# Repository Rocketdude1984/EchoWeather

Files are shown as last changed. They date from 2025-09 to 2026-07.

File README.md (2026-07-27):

# EchoWeather: DIY weather station and app
A personal project to design, build, and program a working weather station that connects to a database and smart phone app. Collected data will then be used to train an AI model that will predict future weather variables.

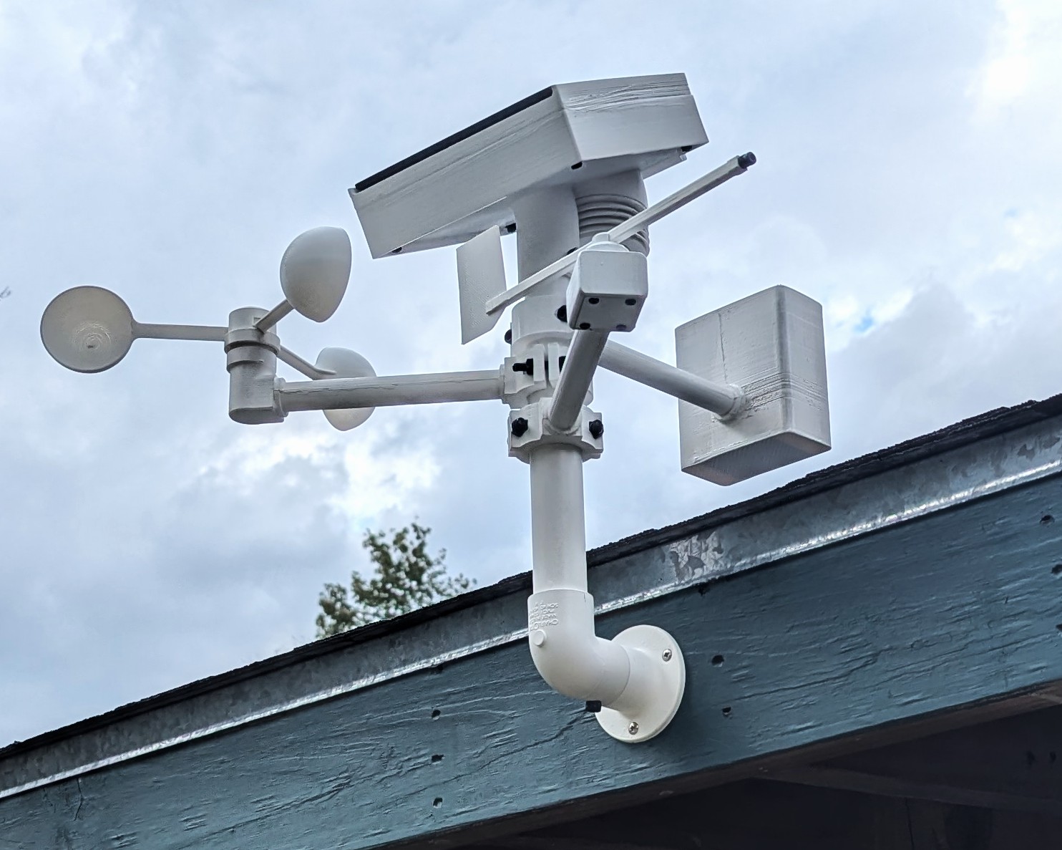
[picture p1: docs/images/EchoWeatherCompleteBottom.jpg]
Diagram


## Weather Variables

* Wind Speed
* Wind Direction
* Temperature
* Humidity
* Pressure
* Ambient Light
* UV Light
* Rain

## Sensors and Components
1. XIAO ESP32C3: https://www.amazon.com/dp/B0DGX3LSC7?ref=ppx_yo2ov_dt_b_fed_asin_title&th=1
2. BME280 breakout module: https://www.amazon.com/dp/B0DHPCFJD6?ref=ppx_yo2ov_dt_b_fed_asin_title&th=1
3. AS5600 Magnetic Encoder: https://www.amazon.com/dp/B094F8H591?ref=ppx_yo2ov_dt_b_fed_asin_title&th=1
4. Solar Power Manager Board: https://www.amazon.com/dp/B0FQP915R9?ref_=ppx_hzsearch_conn_dt_b_fed_asin_title_2
5. LTR390-UV Ultraviolet Sensor: https://www.amazon.com/dp/B0CHJL143Z?ref=ppx_yo2ov_dt_b_fed_asin_title&th=1
6. VEML7700 Ambient Light Sensor: https://www.amazon.com/dp/B09KGYF83T?ref=ppx_yo2ov_dt_b_fed_asin_title
7. 6V3W Waterproof Solar Panel: https://www.amazon.com/dp/B0CS364JGG?ref=ppx_yo2ov_dt_b_fed_asin_title&th=1

## Modules
The weather station will be built in 4 modules.
1. Power and basic variables (Main module)
2. Wind vane
3. Anemometer
4. Rain gauge

Each module will be connected together to the main module where all collected data will be sent to the cloud.

## Power
The station will be powered by two 18650s in parallel. To keep the battery charged, the station will have a built in 6V3W solar panel that charges the battery through a solar power management board.

## Materials
Most of the station is printed with PETG which should be able to withstand fairly high outdoor temperatures and resist fading or cracking. 1" PVC pipe is used for the main support to hold each module of the station. For extra UV protection a few coats of white spray paint will be used.

## Code
Download full code folder and make sure to replace the credentials in cred.h with your own information for WiFi and google sheet connectivity. Read this article for getting IDs and keys for the credentials: [https://randomnerdtutorials.com/esp32-datalogging-google-sheets/].

## App
The app was designed in MIT App Inventor and I have included the .aia file that you can import into App Inventor and configure to your project. (the only required configuration is the URL to your app script for sheets, re: docs/Google_sheet_setup).

## Calibration 
After allowing the system to run for a few months I compared known weather data from reliable sources with the data gathered from the station. Most values were close to the true ones, but I did calculate some scaling factors for the station. See the Calibration and Changes page under docs.

## One-year Thoughts
The Station has been running near constant for a year now (a few hiccups caused me to miss a few days). I did some things right and lot wrong that I would do different if I ever made another station.

### What I did right
- The Wind direction sensor worked perfectly.
- The Rain sensor did work, but how on that in the next section.
- The batteries only lost power 2 times (once because of an extended cloudy period > 7 days of cloulds, and once because of the batteries overheating).
- The app worked great for the whole test period
- The PETG and paint held up great even in the extreme heat.
- The enclosure was completely waterproof.

### What I would do differently
- lithium-polymer was the wrong choice for the Texas heat, I had 2 sets of lipos overheat and become unusable because of the Texas heat and the lack of active or passive cooling. I would instead switch to LiFePo4 cells with a thermal sensor on the cells that would activate a small fan to vent out the hot air in the enclosure.
- The ESP32C3 Xiao board just didn't have enough GPIO pins, I had to use a boot pin for the rain sensor that could sometimes cause the station to not turn on if it was stuck high. I would use a standard ESP32 dev board.
- I would make sure to have a quick-disconnect function for the staion and the mount. I had to take the station down quite a few times and unscrewing the mount and holding the station was very difficult to do on a ladder. I would make sure to use a connection that only needed a single thumb screw to remove the station.
- I would also make a custom holder for the staion when I am working on it because it I did not like the way the anemometer and wind vane would bend on when the station sat on the desk.
- The BME sensor did not prove to be super accurate either. The temperature was always 10-15 degrees higher than the true temperature in temps over 90 degrees, but yet correct under about 80 degrees. The humidity sensor just has been 100% for about 3 months and not changed, but it never seemed that accurate before.
- The lux sensor also didn't really correlate to any real values, but it did work for relative measurements.
- The solar board I installed half-way through the test was much better than the first board I had, but I would need to find one that works with the lower voltage of the LiFePo4 cells I would use.
- I would also be great for the station to start a new spreadsheet for logging data every year because the app took a while to load a years worth of data from the spreadsheet.

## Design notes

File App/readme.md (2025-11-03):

# App Notes

The app for the EchoWeather system was design in Gimp and built in MIT App Inventor

I could not include the APK because if you want to make this project you will have to edit a URL in App Inventor in order to connect to your app script that fetches data from your Google Sheet (re: fig. 3).

## Displayed Values
* Temperature
* Humidity
* Pressure
* Average wind speed
* Gust wind speed
* Cardinal wind direction
* rain rate in in/hr
* light level
* UV level
* Battery Voltage
* Location of Weather Station
* Last updated time
* Icon of type of weather based on light, rain, and temperature
* 24 Hour high and low values for temperature, wind, rain, and humidity

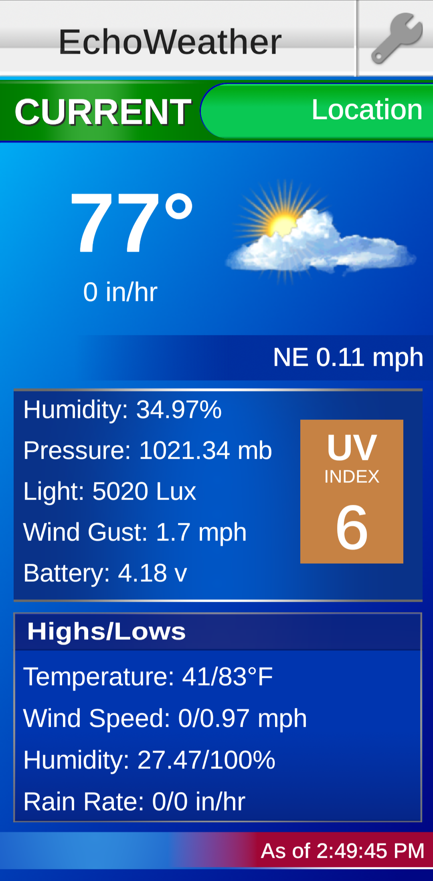
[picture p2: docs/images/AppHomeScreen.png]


fig. 1 - EchoWeather App homescreen

The App also has a settings screen for changing units on temperature, wind speed, and daylight saving or standard time, see fig. 2.

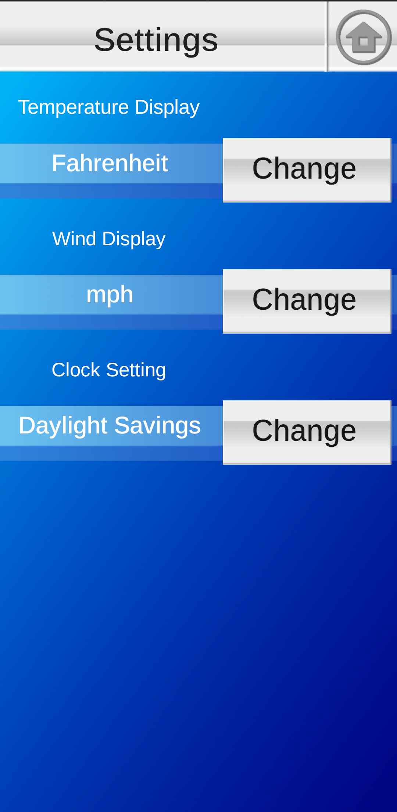
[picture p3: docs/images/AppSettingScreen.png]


fig. 2 - The settings screen for the app to change select units and time

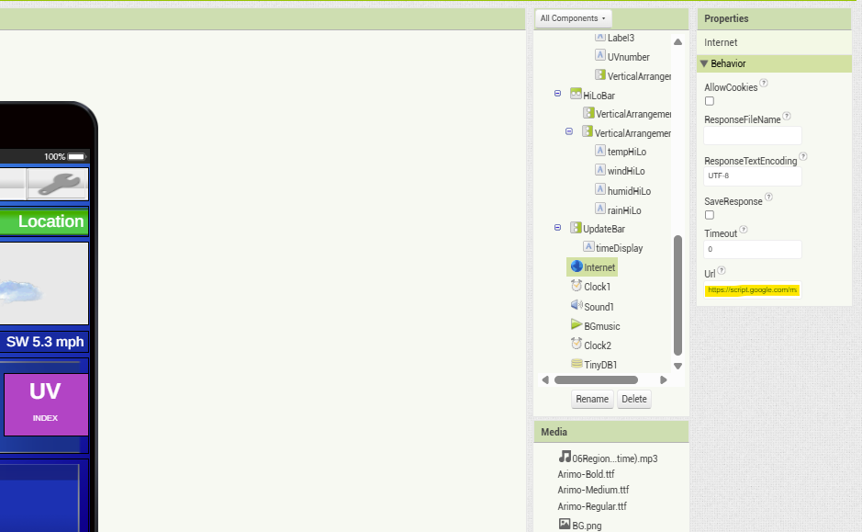
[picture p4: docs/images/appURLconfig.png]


fig. 3 - The URL component you must change to match your own app script in App Inventor

See Google Sheets setup in the docs folder on how to get this URL for your own project.

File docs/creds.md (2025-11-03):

## References
Project inspired by: Nikodem Bartnik, Weather Station is The Best DIY Project EVER. https://youtu.be/U0kPgFcALac?si=J3OKKQZrQx6dV7NR

3D models: wt29, Anemometer, Windvane and Raingauge - 3D Printed and ESP8266 Enabled. Internet Connected and Logging. https://www.instructables.com/Anemometer-3D-Printed-With-Internet-Logging/

App resources:
App images: The Spriter's Resource: http - //www.spriters-resource.com/wii/forecastchannel/asset/68551/?source=genre
App Background music: KHinsider.com - https://downloads.khinsider.com/game-soundtracks/album/wii-forecast-channel
App design software: MIT App Inventor - https://appinventor.mit.edu/

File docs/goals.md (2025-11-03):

# Project Goals

- [x] Design, build, and program a small weather station using a variety of sensors.
- [x] Construct station using 3D printable prints and cheap, commercially available parts.
- [x] Design a smart phone app to display current weather variables.
- [ ] Build and deploy multiple stations across wide geographic area.
- [ ] Build and train AI model using collect weather data for future weather predictions.
- [ ] Update smart phone app to include predicted forecast.

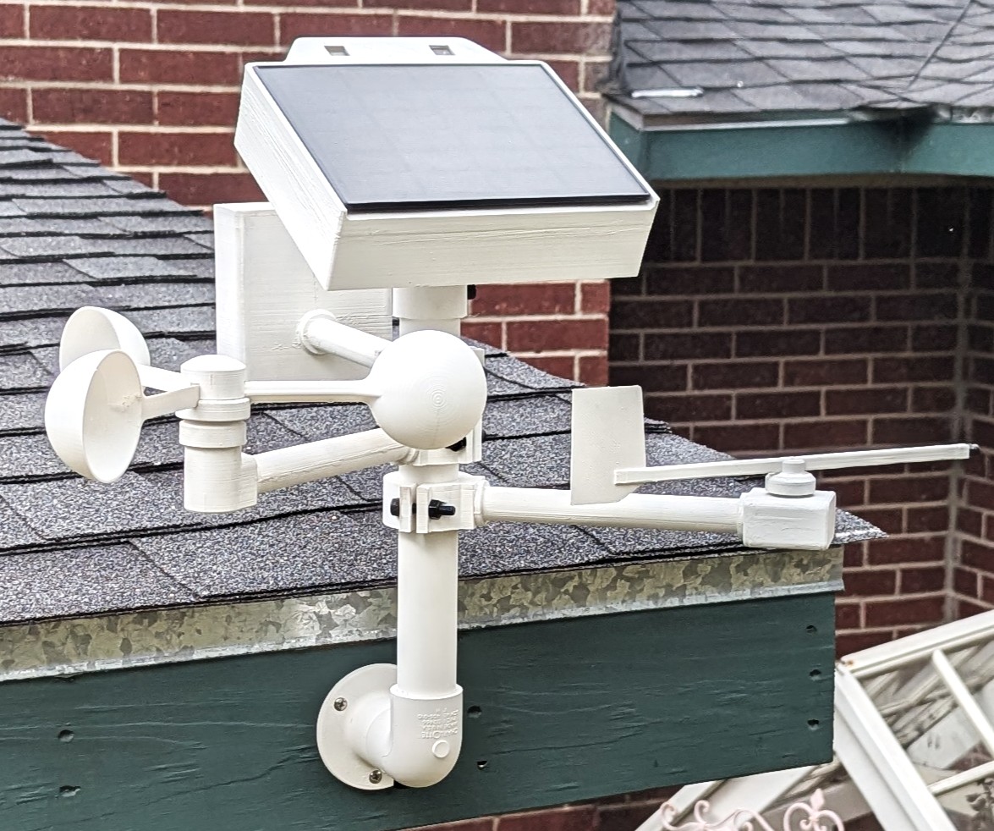
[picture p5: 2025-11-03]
docs/images/EchoWeatherCompleteTop.jpg

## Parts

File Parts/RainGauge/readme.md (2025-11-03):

# Notes

## Construction

1. Print all parts of Rain Gauge MAKE SURE TO USE "LINES" OR SIMILAR INFILL PATTERN FOR TOP AND BOTTOM GRID PRINTS AND SET TOP AND BOTTOM WALLS TO 0. There should be no top or bottom walls to these parts as they are supposed to let water through while blocking wasp and other insects from making nest inside the rain gauge. see fig. 1.
2. Drill, file, and sand parts to ensure good fittment between prints.
3. Install 2 ball bearings into EchoWeather_bucket.
4. Cut 4mm to length to span bucket and fulcrum parts.
5. Use washers to act as spacers and to reduce frictiion between fulcrum and bucket
6. Install magnet in bucket WITH SOUTH POLE FACING OUTWARDS.

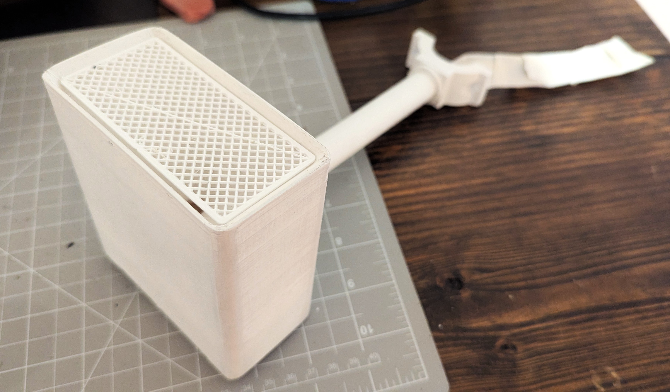
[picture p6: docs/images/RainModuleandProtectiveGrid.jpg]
Diagram


fig. 1 - Completed Rain Gauge with protective grids for insect protection

## Components

* 2x5mm round magnet
* (2) 8x4x3 ball bearings
* 4mm steel rod
* Assembled support rod (see support rod notes)

## Specs

This setup was calculated from test to be about 0.7mm (0.028in) for each tip of the bucket.
This module is not very sensitive to rain, and will probably be re-designed in the future. 
With a 5-min measuring interval, this module can only measure rain rates greater than 0.33 in/hr.

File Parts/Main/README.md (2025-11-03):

# Main Notes
## Main Box
1. Ensure there is enough glue to waterproof components.
2. Glue all parts together, unless screws or bolts are used, in this case use no glue.
3. Use Silicone based adhesive to seal joints.
4. Finish with bright white, satin spray paint.
5. Glue milk carton squares to cover UV and Lux sensor.

Components:
* (4) - M4x7 socket head bolts -- for holding bottom to enclosure
* (7) - M4x5x5 heated threaded inserts -- 4, for bottom bolts, 3 for stevenson screen connection
* (2) - M6x12 socket head bolts -- for securing box to PVC pip mounts at both ends
* (2) - M6 nuts
* (2) - M2.5x6 pan head bolts -- for VEML7700
* (2) - M2x4 socket head bolts -- for LTR390-UV
* 1/16" thick silicone sheet cut to fit channel in top of box (see image below)
* 1/16" thick acrylic sheet cut to fit viewing ports for light sensors (see image below)
* (2) - 18650 battery holders
* 1.5" OD PVC pipe (about 10" long)
* 1.5" 90° elbow fitting -- if mounting on a vertical surface
* About 3/4" square pieces of cut plastic milk gallon (to act as light diffuser for ambient light sensor and UV sensor).

*See electrical (WIP) for electrical components in main box.*

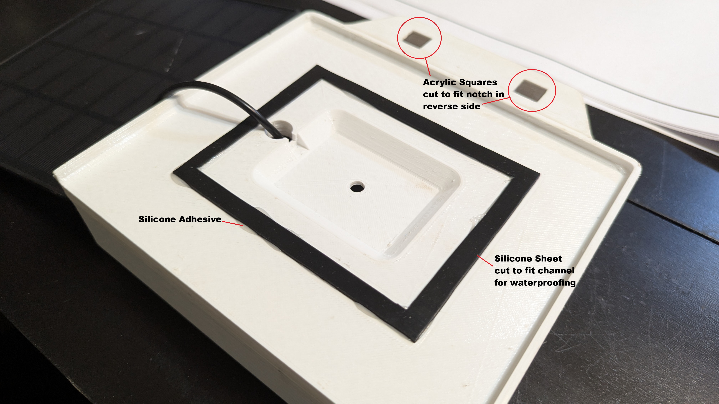
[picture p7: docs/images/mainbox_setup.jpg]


fig. 1 - waterproofing measures for Main Box

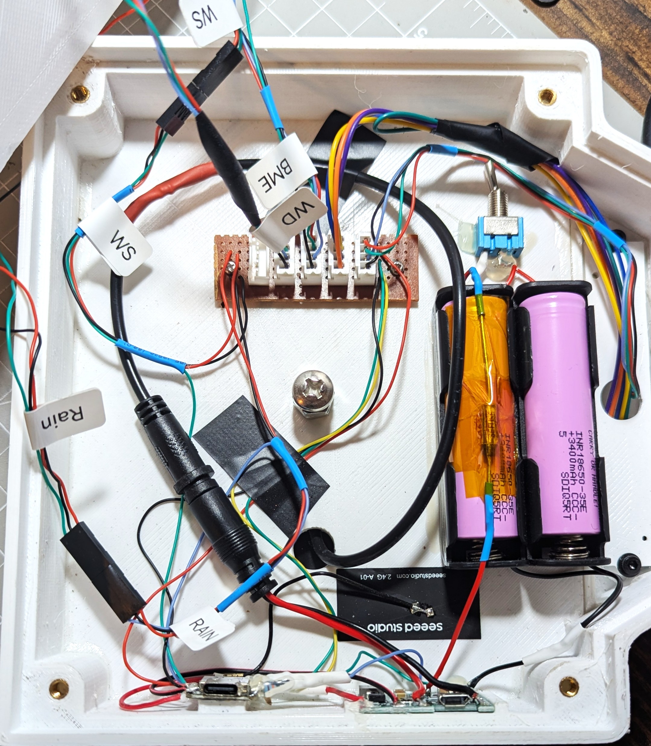
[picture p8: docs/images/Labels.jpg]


fig. 2 - Layout of components in Main Box

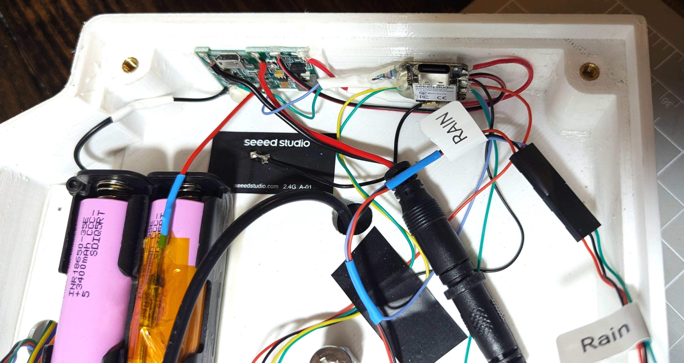
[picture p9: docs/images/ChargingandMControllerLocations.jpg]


fig. 3 - Location of Charging module and Microcontroller

## Stevenson Screen:
1. Print (4) total Rings for the stevenson screen (There is only one ring .stl file because they're of course identical)
2. Glue mounting plate for BME280 to top of stevenson screen (this is the only component for the screen that needs glue).

Components:
* (3) M4x30 socket head bolts
* M3x8 socket head bolt -- for mounting BME280
* M3 nut
* 1-3/4" x 1-5/16" sink strainer washer

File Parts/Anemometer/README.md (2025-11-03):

# Notes

REQUIRED FILES FOR ANEMOMETER
Download the following parts from the anemometer project by [wt29](https://github.com/wt29):
- [AnemometerBaseCap.stl](https://github.com/wt29/Anemometer/blob/main/stl/AnemometerBaseCap.stl)
- [AnemometerRotor.stl](https://github.com/wt29/Anemometer/blob/main/stl/AnemometerRotor.stl)
- [AnemometerRotorCap.stl](https://github.com/wt29/Anemometer/blob/main/stl/AnemometerRotorCap.stl)

These parts did need some minor modification by filing, drilling, and sanding, but they did work.

The EchoWeather_AnemometerEnclosure was used just as an adapter to make wt29's parts with this project's support rod.
New wind cups were also designed (EchoWeather_WindCupv3). These redesigned cups were more sensitive to lighter winds.

## Construction
1. Print 3 total wind cups
2. Some drilling is required to allow the 3144 hall-effect sensor to fit flush with surface of print (AnemometerBaseCap)
3. 3. Glue two 5x2mm magnets into bottom divots of rotor. MAKE SURE THE SOUTH POLE OF MAGNET IS FACING OUTWARD, the 3144 can only detect south magnetic poles, I used a test set up with an arduino and the 3144 sensor to know which pole was south.
4. Use a 4mm Threading die to cut threads into 4mm rod, about a 1/4".
5. Cut the rod to length to be used as axle.
6. Glue wind cups into rotor, ensuring each cup is pushed in all the way and level.
7. Glue 3144 sensor into rotor base cap and solder wiring to leads, BEFORE gluing the base cap to the anemometer enclosure.
8. Insert single ball bearing into rotor (bottom). printed part has slots for 2 bearings, but in testing 1 bearing provided less friction and more sensitivity.
9. Insert 4mm rod through rotor assembly and then into the base assembly. (I put a small washer in-between the two assesmblies to reduce friction)
10. Use lubricating oil to reduce friction between rotor and base at the washer.

## Components
- (2) 5x2mm magnets
- 8x4x3 ball bearing
- 4mm stainless steel rod, cut to length
- 3144 hall-effect sensor
- Support rod assembly (see supoort rod notes)

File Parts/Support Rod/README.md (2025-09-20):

# Notes for Support Rod
1. print (2) total support Rod halves to make the completed rod.
2. Enclose wiring for sensor in support rod BEFORE assembly.
3. Using glue to fasten the two support rod halves together and then the rod to the inner clamp.
4. The Outer clamp is held in with bolts and nuts.

# Components
* (2) - M6x25 socket head bolts
* (2) - M6 nuts

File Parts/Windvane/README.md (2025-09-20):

# Wind Vane

## Notes
1. Fasten the face, lid, and enclosure parts with waterproof adhesive.
2. Secure AS5600 sensor with IC side facing shaft.
3. Cut 4mm rod to length.
4. Glue included magnet with AS5600 to bottom of 4mm rod.
5. Use M4 nuts, washsers, and bolt to move CoM of wind vane to the mounting hole.
6. Use M6 washer to act as spacer between inner and outer rotor parts.

Components
- (4) M4x8 bolts - for securing AS5600 to enclosure
- (4) M3x8 bolts - for bottom lid
- 4mm stainless steel rod cut to length - for axle of wind vane
- M4x(8mm-16mm) bolt - for balancing wind vane, may need extra nuts or washers (I used M4x12 bolt with (2) M4 nuts).
- (5) M4x5x5 heated, threaded inserts - 4 for AS5600 mounting and 1 for the balancing bolt of wind vane
- (4) M3x4x4.2 heated, threaded inserts - for the bottom cover of the wind vane
- (2) 8x4x3mm ball bearings - one in each divot of the inner rotor part.
- Support rod assembly (see support rod notes)

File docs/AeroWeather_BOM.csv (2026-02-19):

Option 1
Component | Quantity | Cost | Cost/unit | Notes
BME280 | 2 | $12.89 | $4.30 | Temperature, Humidity, Presurre
ESP32C3 Xiao | 3 | $19.99 | $6.66 | Controller
LTR390-UV | 1 | $14.60 | $14.60 | UV sensor
PETG filament | 1 | $15.60 | $15.60 | Anemometer, wind vane, enclosure
AS5600 | 3 | $9.99 | $3.33 | Rotary Senor
Bearings 4mmIDx8mmODx3mmH | 10 | $8.69 | $0.87 | Bearings
Solar Power Manger | 1 | $16.29 | $16.29 | Charging and Boost Converter
VEML7700 | 2 | $12.99 | $6.50 | Light Sensor
6w solar panel | 1 | $18.99 | $18.99 | Solar Panel
1inOD PVC pipe | 1 | $5.41 | $5.41 | Mast
1inOD PVC 90 | 1 | $1.48 | $1.48 | Elbow
Krylon Spray Paint | 3 | $7.98 | $2.66 | UV protection
18650 Battery Holder | 5 | $5.98 | $1.20 | Holds the single 18650 cell
18650 Cells | 6 | $23.99 | $4.00 | Powers the station
 | Total Cost | $174.87 | $101.88

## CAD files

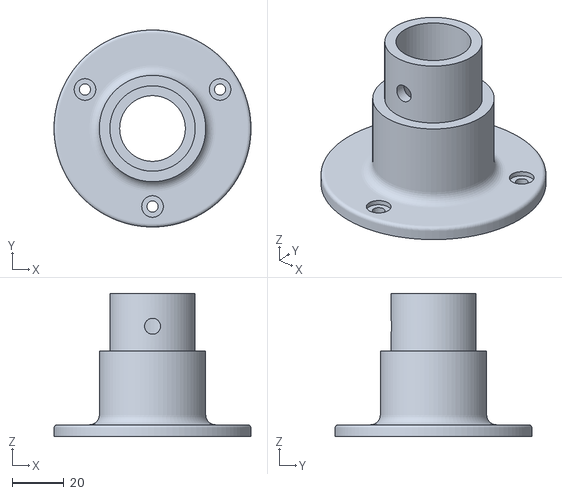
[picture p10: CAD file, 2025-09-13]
Parts/Main/Prints/EchoWeather_Main_PipeAdapter.stl
76.2 x 76.2 x 55.4

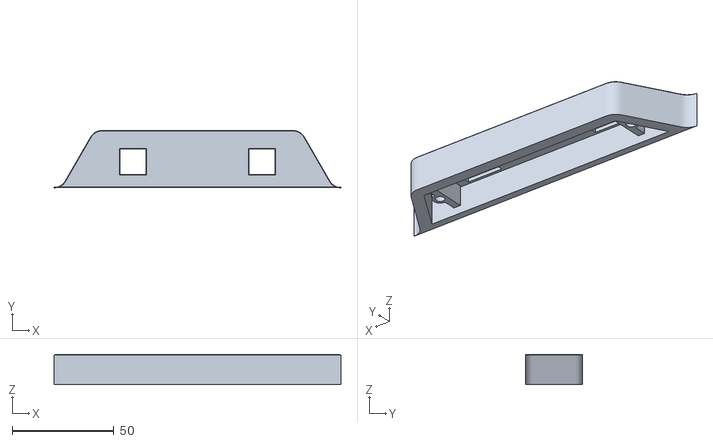
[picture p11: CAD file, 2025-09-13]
Parts/Main/Prints/EchoWeather_Main_LightSensorModule.stl
141.4 x 28.1 x 15.0

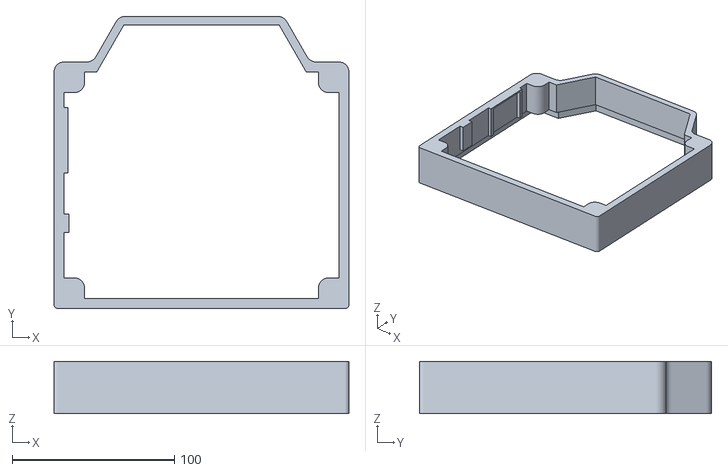
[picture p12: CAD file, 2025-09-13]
Parts/Main/Prints/EchoWeather_Main_Enclosure.stl
182.0 x 180.2 x 32.4

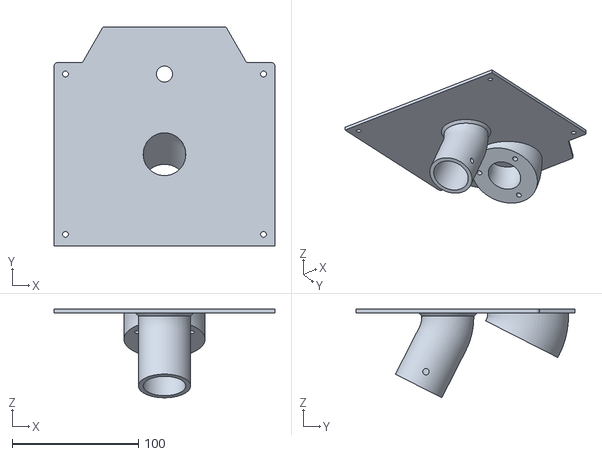
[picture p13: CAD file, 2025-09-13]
Parts/Main/Prints/EchoWeather_Main_Bottom.stl
175.0 x 173.3 x 70.2

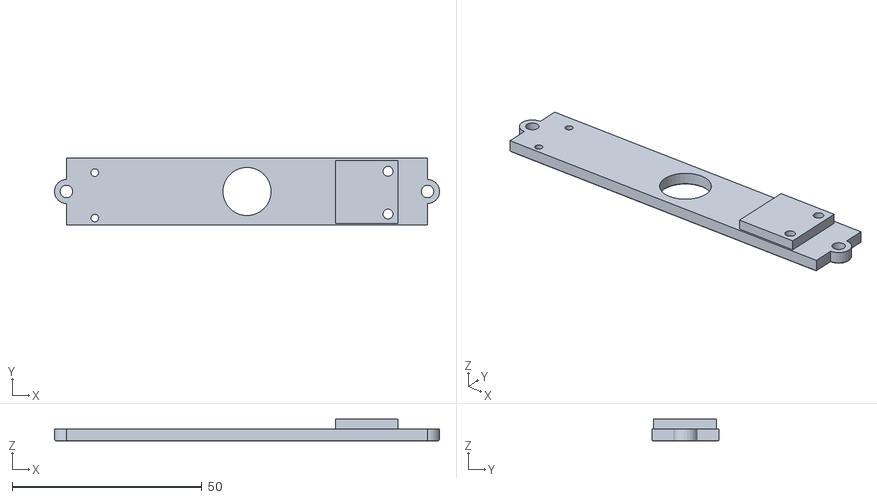
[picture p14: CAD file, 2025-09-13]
Parts/Main/Prints/EchoWeather_Main_LightSensorHolder.stl
101.6 x 17.8 x 5.71

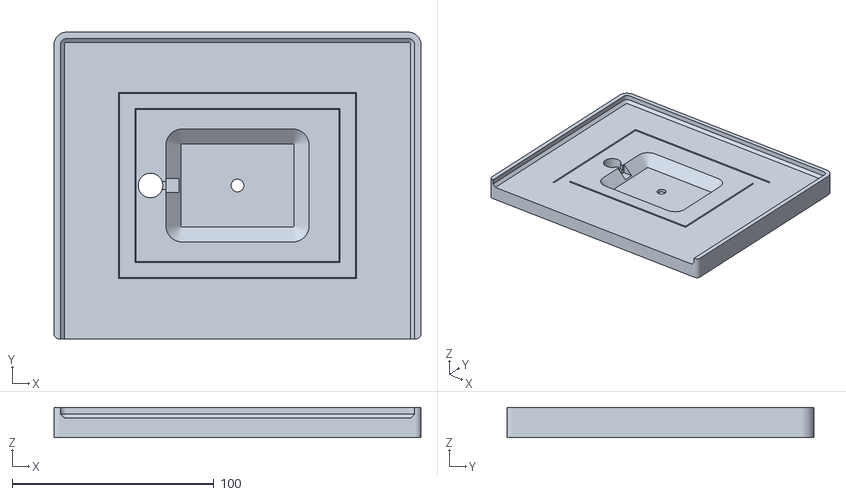
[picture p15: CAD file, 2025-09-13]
Parts/Main/Prints/EchoWeather_Main_Lid.stl
182.0 x 152.1 x 15.0

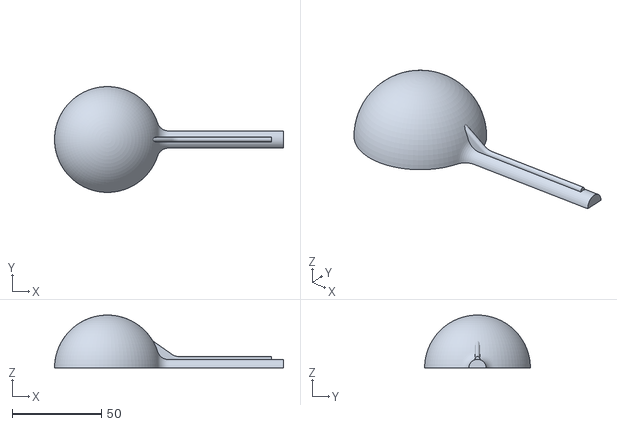
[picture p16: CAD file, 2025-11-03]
Parts/Anemometer/Prints/EchoWeather_WindCupv3.stl
128.0 x 59.1 x 29.6

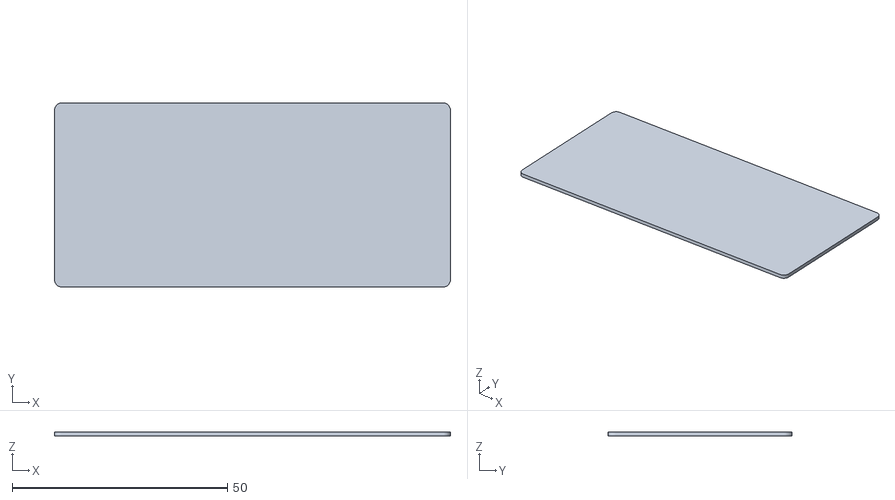
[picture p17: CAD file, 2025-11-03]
Parts/RainGauge/Prints/EchoWeather_RainGauge_TopGrid.stl
92.0 x 42.7 x 1.00

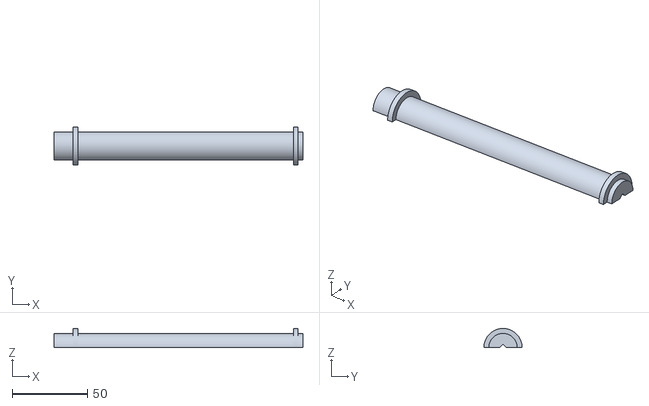
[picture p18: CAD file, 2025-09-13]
Parts/Support Rod/Prints/EchoWeather_SupportRod.stl
165.1 x 25.4 x 12.7

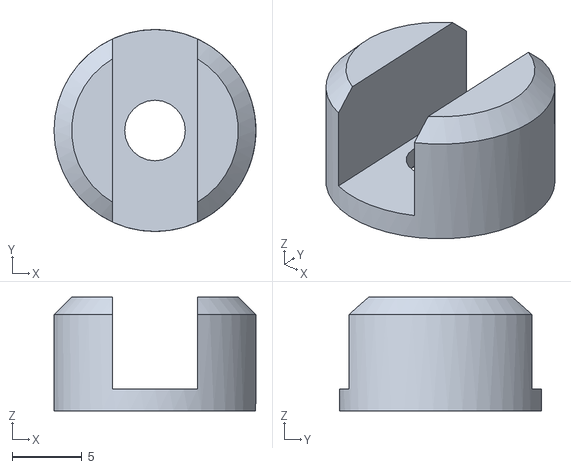
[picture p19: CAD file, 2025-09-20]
Parts/Windvane/WindVane_Prints/EchoWeather_WindVane_Holder.stl
14.5 x 14.5 x 8.19

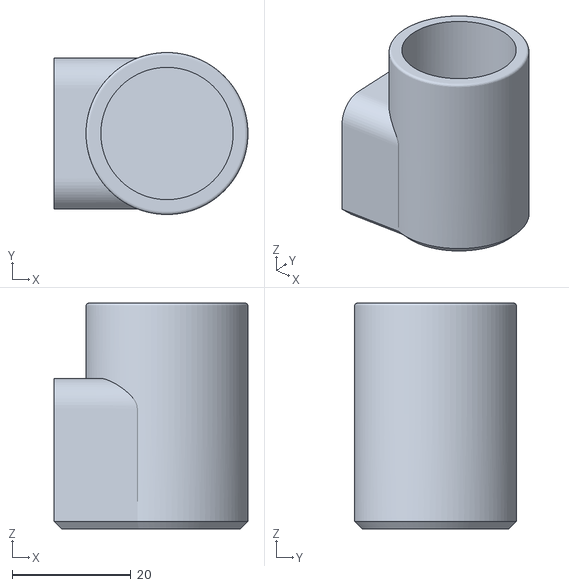
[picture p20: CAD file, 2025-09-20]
Parts/Anemometer/Prints/EchoWeather_AnemometerEnclosure.stl
32.7 x 27.3 x 38.1

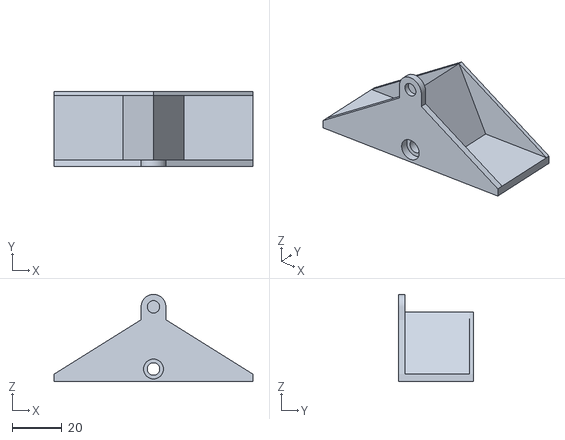
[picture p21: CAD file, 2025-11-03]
Parts/RainGauge/Prints/EchoWeather_Bucket.stl
80.0 x 30.0 x 35.1

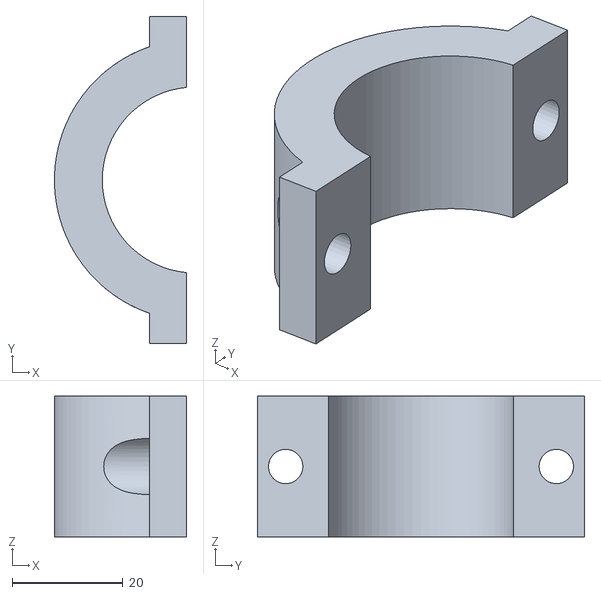
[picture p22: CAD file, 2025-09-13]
Parts/Support Rod/Prints/EchoWeather_OuterClamp.stl
23.8 x 58.9 x 25.4

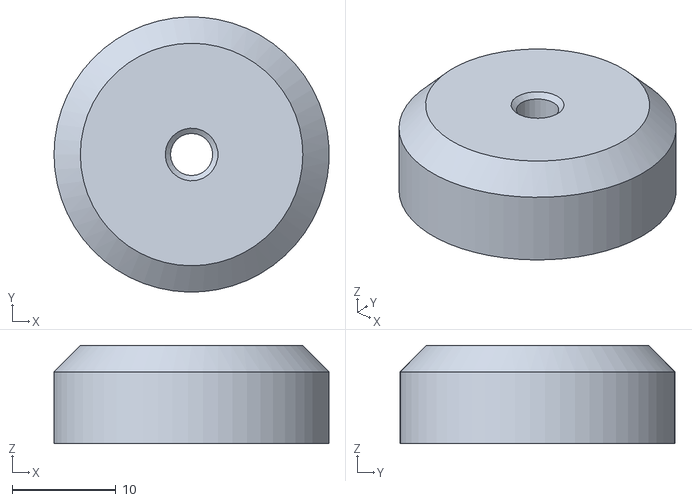
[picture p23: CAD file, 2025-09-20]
Parts/Windvane/WindVane_Prints/EchoWeather_WindVane_OuterRotor.stl
26.5 x 26.5 x 9.45

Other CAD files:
Parts/Main/Prints/EchoWeather_StevensonScreen_Ring.stl
Parts/RainGauge/Prints/EchoWeather_RainGauge_Funnel.stl
Parts/Support Rod/Prints/EchoWeather_InnerClamp.stl
Parts/Windvane/WindVane_Prints/EchoWeather_WindVane_InnerRotor.stl
Parts/Anemometer/Models/EchoWeather_AnemometerEnclosure.f3d
Parts/Anemometer/Models/EchoWeather_WindCup v3.f3d
Parts/Main/Models/EchoWeather_Main.f3z
Parts/Main/Models/EchoWeather_Main_PipeAdapter_.f3d
Parts/Main/Models/EchoWeather_StevensonScreen.f3z
Parts/Main/Models/PowerBox.blend
Parts/Main/Prints/EchoWeather_StevensonScreen_Bottom.stl
Parts/Main/Prints/EchoWeather_StevensonScreen_Lid.stl
Parts/Main/Prints/EchoWeather_StevensonScreen_MountingPlate.stl
Parts/RainGauge/Models/EchoWeather_RainGauge.f3z
Parts/RainGauge/Prints/EchoWeather_RainGauge_BottomGrid.stl
Parts/RainGauge/Prints/EchoWeather_RainGauge_Fulcrum.stl
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

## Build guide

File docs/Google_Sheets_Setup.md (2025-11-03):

# Google Sheet Setup

This project use google sheets as the data collection software for the weather station, that way there is no need to open a port to the web using NGROK or a similar provider.
This solution to me seems the most veristile as it allows multiple stations to send data to the same spread sheet for collection making it easier to possiblly train an AI model later.

## 1. Setting up Your Google Sheet and getting Credentials
Random Nerd Turtorials has a great and beginner friendly article on how to setup a Google sheet for the project and get the required credentials to input into the creds.h file of the code.

## 2. Creating an app script for your sheet
Once you have a sheet created and input all of the required credentials into the cred.h file, you have to set up an app script on your sheet that send data to the app when it is requested.
Copy the code from the GetData file in the docs folder and input the code into a new app script.
Deploy this script (it will require some verfication from you to do so, but this will only be allowing you with the URL to access the weather data). 
Once the script is deployed makes sure to copy the web app URL. This is the URL you will input into the Internet Module of the app in MIT App Inventor (see the App folder for more information). 

This script fetches the last 144 rows of data (or if less than 144 all the rows) and sends JSON data to the app.

Diagram

fig. 1 - the sheet setup with headers used, this is how the microcontroller will send the weather data. You can of course change the order of columns but this will have to be done in the arduino code (EchoWeather_v1.ino).

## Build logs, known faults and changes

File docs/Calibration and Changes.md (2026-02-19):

# Calibration and Changes

After allowing the station to sit outside and face harsh sunny days, long periods of overcast, and fierce rain and wind, I was able to calibrate the sensors to more accurately measure weather data. I Also had to repair and make changes to some of the design.

## Calibrations

All scaling and offset values are already set in the EchoWeather_v1.ino file.

- UV scaling = 0.0285
- Pressure scaling = 1.003
- Light Level factor 1 = 1.8
- Light Level factor 2 = 7

The wind, humidity, and temperature sensors were all close enough to the true values to not need calibration. 
The Light sensor had a strange measuring problem were under a threshold the values were close to the true values, but after that threshold the values were far to small.
To fix this I included a small change in the getLuxLevel function to apply different scaling factors depenending on a threshold set by measurement (15000):

```
int GetLuxLevel(){
  int lux = veml.readLux();
  if (lux > 15000){
    lux = lux * lightScale2;
  } else {
    lux = lux * lightScale1;
  }
  delay(500);
  return lux;
}
```

## Changes

After some strong winds and storms the station did suffer small damage and actually had a software problem which caused the battery charging board to malfunction and killed the charger. The biggest issue through was not a weather problem but a connectivity issue.

### Weather damage
- I had placed small pieces of milk carton to act as diffusion screen for the UV and light Level sensors, these both fell off during heavy wind due to weak glue bonds. I used gorilla glue to fasten this time and so far they have held on.
- The fastener (bolts and nuts) had already started rusting so I replaced the rusty ones and spray painted new hardware with a rust resistant paint.
- A series of cloudy days (about 6 days of overcast) and a loss of internet connection caused the station to get stuck in a loop trying to connect to the Google Sheets API and this not only drained the batteries, but caused the TP4056 charging board to stop recharging.

### Improvements
Because the station would no longer charge, I had to remove it and diagnose the issue. I found that the TP4056 board was no longer functioning. 
I did not simply replace it with another of the same boards because this issue would probably happen again.
Instead this time I went with a more robost charging system. An actual solar charging board.

Solar Power Manager 5V, JEITA Li-ion Battery Charger Module with Dual USB & 5V/3.3V Output, for Solar Panel Charging
[Solar Charging Board - AmazonUS](https://www.amazon.com/dp/B0FQP915R9?ref_=ppx_hzsearch_conn_dt_b_fed_asin_title_2)

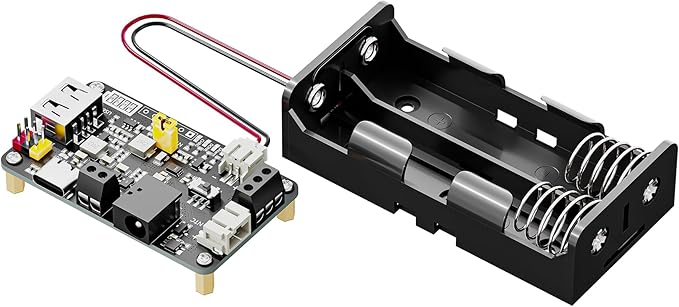
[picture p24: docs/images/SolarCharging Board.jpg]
Diagram


This board was far superior to the simple TP4056. It had much more protection (Thermal, overdischarge, under voltage, etc) it had a better built-in converter and the setup was much simpler. I wish I would have used it from the start.

So far this new charging board has worked perfectly for over 2 months and has never let the batteries dip below 3 volts even on several cloudy days (about 5 days straight of overcast at one time).

### Code Changes
After this testing I determined that because of using the 2, 18650s cells the station had enough capacity to run with 10 minute measuring intervals for wind and rain, instead of 5min measuring and 5min sleeping. This change improved the acccuracy of the wind speed, wind gust, and rain rates for the station.

This change also makes the controller reset for every measuring period to hopefully elimanate any chance of it becoming stuck in a connection loop like last time.

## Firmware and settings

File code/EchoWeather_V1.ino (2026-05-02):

#include "AS5600.h"
#include <Adafruit_Sensor.h>
#include <Adafruit_BME280.h>
#include "Adafruit_VEML7700.h"
#include "LTR390.h"
//#include <esp_sleep.h>
#include "WiFi.h"
#include "Creds.h"
#include "time.h"
#include <sys/time.h>
#include <ESP_Google_Sheet_Client.h>
#include <GS_SDHelper.h>

// Wind, rain, and battery pin definitions
#define windPin 10
#define rainPin 21
#define batteryPin 2

// Token Callback function
void tokenStatusCallback(TokenInfo info);

// NTP server to request epoch time
const char* ntpServer = "pool.ntp.org";

// Variable to save current epoch time
unsigned long epochTime; 

bool connected = false;

// Function that gets current epoch time
unsigned long getTime() {
  time_t now;
  struct tm timeinfo;
  if (!getLocalTime(&timeinfo)) {
    //Serial.println("Failed to obtain time");
    return(0);
  }
  time(&now);
  return now;
}

AS5600 as5600;
Adafruit_BME280 bme; // I2C
Adafruit_VEML7700 veml = Adafruit_VEML7700();
UDOUBLE UV,ALS;

// Calibration Factors
float UVscale = 0.0285;
float lightScale1 = 1.8;
float lightScale2 = 7;
float tempScale = 1;
float tempOff = 0;
float presScale = 1.003;
float presOff = 0;
float humidScale = 1;
float humidOff = 0;
int directionOffset = -270; //degree offset

volatile unsigned long windCount = 0;
volatile unsigned long rainCount = 0;

unsigned long startTime = millis();
unsigned long windPulseTime = millis();
unsigned long windElapsedPulse = 0;
unsigned long measureTime = 591; // Time in Seconds 591(10 mins, extra delay for WiFi connection) -----------------------------------<<<<<<
//unsigned long restTime = 20; // Time in Seconds

float gustWindSpeed = 0;
float maxGust = 0;

// interrupt for wind pulses and calculating wind gust speed
void IRAM_ATTR onWindPulse() {
  windElapsedPulse = millis() - windPulseTime;
  gustWindSpeed = 1.654 / (windElapsedPulse/1000.0);
  if (gustWindSpeed > maxGust){
    maxGust = gustWindSpeed;
  }
  windPulseTime = millis();
  windCount++;
}

// interrupt for counting rain pulses
void IRAM_ATTR onRainPulse() {
  rainCount++;
}


void setup() {
  Serial.begin(115200);

  delay(500);
  //Serial.print("Wake Interval: ");
  //Serial.print(restTime);
  //Serial.print("s, ");
  Serial.print("Measure Interval: ");
  Serial.print(measureTime);
  Serial.println("s");
  //esp_sleep_enable_timer_wakeup(wakeUpInterval * 1000000);
  Wire.begin();

// Wind Direction Setup
  as5600.begin(4);  //  set direction pin.
  as5600.setDirection(AS5600_CLOCK_WISE);  //  default, just be explicit.
  //int b = as5600.isConnected();
  //Serial.print("Connect: ");
  //Serial.println(b);
  delay(100);

// BME setup
  unsigned status;
  status = bme.begin(0x76);
  bme.setSampling(Adafruit_BME280::MODE_FORCED,
                    Adafruit_BME280::SAMPLING_X1, // temperature
                    Adafruit_BME280::SAMPLING_X1, // pressure
                    Adafruit_BME280::SAMPLING_X1, // humidity
                    Adafruit_BME280::FILTER_OFF   );   
  if (!status) {
    Serial.println("Could not find a valid BME280 sensor, check wiring, address, sensor ID!");
    Serial.print("SensorID was: 0x"); Serial.println(bme.sensorID(),16);
    Serial.print("        ID of 0xFF probably means a bad address, a BMP 180 or BMP 085\n");
    Serial.print("   ID of 0x56-0x58 represents a BMP 280,\n");
    Serial.print("        ID of 0x60 represents a BME 280.\n");
    Serial.print("        ID of 0x61 represents a BME 680.\n");
    //while (1) delay(10);
  }

  // veml Setup
  if (!veml.begin()) {
    Serial.println("Sensor not found");
  }

  veml.setGain(VEML7700_GAIN_1_8);      // 1/8
  veml.setIntegrationTime(VEML7700_IT_25MS); // 25 ms
  veml.interruptEnable(false);

  //UVSetup
  if(LTR390_Init() != 0){
    //Serial.print("init err!!!");
    while(1);
  }
  LTR390_SetIntVal(5, 20);

  //Wind speed setup
  pinMode(windPin, INPUT_PULLUP);
  attachInterrupt(digitalPinToInterrupt(windPin), onWindPulse, FALLING);

  //Rain Gauge Setup
  pinMode(rainPin, INPUT_PULLUP);
  attachInterrupt(digitalPinToInterrupt(rainPin), onRainPulse, FALLING);

  //Battery Voltage Setup
  pinMode(batteryPin, INPUT);

}

void loop() {

if (!connected){
// Measuring Phase for rain and wind speed
  unsigned long cycleStart = millis();
  unsigned long elapsedTime = 0;
  while (elapsedTime <= measureTime*1000){
    elapsedTime = millis() - cycleStart;
    delay(1);
  }
  connected = ConnectToSheets();
}
if (!connected) return;
  bool ready = GSheet.ready();

if (ready){
  // Get sensor values
    int windDegree = GetWindDegree();
    String windCardinalDirection = GetWindCardinalDirection(windDegree);
    float temperatureF = (bme.readTemperature() * 1.8 + 32) * tempScale + tempOff;
    float pressure = bme.readPressure() / 100.0F * presScale + presOff;
    float humidity = bme.readHumidity() * humidScale + humidOff;
    int lightLevel = GetLuxLevel();
    int UV = LTR390_UVS()*UVscale;
    float windSpeed = (float(windCount)/float(measureTime))*1.66;
    float rainRate = float(rainCount)/float(measureTime)*99.216;
    float batteryVoltage = GetBatteryVoltage();
    epochTime = getTime();
    
  // Print Values
    /*
    Serial.print("Wind Direction Degrees: ");
    Serial.print(windDegree);
    Serial.println("°");
    Serial.print("Wind Cardinal Direction: ");
    Serial.println(windCardinalDirection);
    Serial.print("Temperature: ");
    Serial.print(temperatureF);
    Serial.println("°F");
    Serial.print("Pressure: ");
    Serial.print(pressure);
    Serial.println("hPa");
    Serial.print("Humidity: ");
    Serial.print(humidity);
    Serial.println("%");
    Serial.print("Light Level: ");
    Serial.print(lightLevel);
    Serial.println("Lux");
    Serial.print("UV Level: ");
    Serial.println(UV);
    Serial.print("Wind speed: ");
    Serial.print(windSpeed);
    Serial.println(" mph");
    Serial.print("Wind Gust: ");
    Serial.print(maxGust);
    Serial.println(" mph");
    Serial.print("Rain Rate: ");
    Serial.print(rainRate);
    Serial.println(" in/hr");
    Serial.print("Battery Voltage: ");
    Serial.print(batteryVoltage);
    Serial.println(" V");
    Serial.println("");
    */

    FirebaseJson response;

    Serial.printf("Free heap: %u bytes\n", ESP.getFreeHeap());

    Serial.println("\nAppend spreadsheet values...");
    Serial.println("----------------------------");

    FirebaseJson valueRange;

    // append values to spread sheet
    valueRange.add("majorDimension", "COLUMNS");
    valueRange.set("values/[0]/[0]", epochTime);
    valueRange.set("values/[1]/[0]", (int)temperatureF);
    addFloat(valueRange, "values/[2]/[0]", humidity);
    addFloat(valueRange, "values/[3]/[0]", pressure);
    valueRange.set("values/[4]/[0]", windDegree);
    valueRange.set("values/[5]/[0]", windCardinalDirection);
    addFloat(valueRange, "values/[6]/[0]", windSpeed);
    addFloat(valueRange, "values/[7]/[0]", maxGust);
    addFloat(valueRange, "values/[8]/[0]", rainRate);
    valueRange.set("values/[9]/[0]", lightLevel);
    valueRange.set("values/[10]/[0]", UV);
    addFloat(valueRange, "values/[11]/[0]", batteryVoltage);
    valueRange.set("values/[12]/[0]", location);

    // check if successfully appended to sheet
    bool success = GSheet.values.append(&response /* returned response */, spreadsheetId /* spreadsheet Id to append */, "Sheet1!A1" /* range to append */, &valueRange /* data range to append */);
    if (success){
        response.toString(Serial, true);
        valueRange.clear();
    }
    else{
        Serial.println(GSheet.errorReason());
    }
    Serial.println();

    delay(5000);

    // go to deep sleep mode ------------------<<<<<<<<<<<<<<
    WiFi.setSleep(true); 
    Serial.println(WiFi.status());
    Serial.println("");
    ESP.restart();
    //Serial.flush();
    //esp_deep_sleep_start();
  }
}

//Battery Voltage Level
float GetBatteryVoltage(){
  return analogReadMilliVolts(2)*0.00147;
  //return map(analogRead(batteryPin),0,2715.0,0,391.0)/100.0;
}

//Light Levels
int GetLuxLevel(){
  int lux = veml.readLux();
  if (lux > 15000){
    lux = lux * lightScale2;
  } else {
    lux = lux * lightScale1;
  }
  delay(500);
  return lux;
}


// Wind direction
int GetWindDegree(){
  int windDegree = as5600.rawAngle() * AS5600_RAW_TO_DEGREES + directionOffset;
  if (windDegree > 360){
    windDegree -= 360;
  } else if (windDegree < 0){
    windDegree += 360;
  }
  return windDegree;
}

// Wind cardinal direction
String GetWindCardinalDirection(int windDegree){
  String cardinal = "ERROR";
  if (windDegree >= 338 || windDegree < 23)
    cardinal = "N";
  if (windDegree >= 23 && windDegree < 68)
    cardinal = "NE";
  if (windDegree >= 68 && windDegree < 113)
    cardinal = "E";
  if (windDegree >= 113 && windDegree < 158)
    cardinal = "SE";
  if (windDegree >= 158 && windDegree < 203)
    cardinal = "S";
  if (windDegree >= 203 && windDegree < 248)
    cardinal = "SW";
  if (windDegree >= 248 && windDegree < 293)
    cardinal = "W";
  if (windDegree >= 293 && windDegree < 338)
    cardinal = "NW";
  return cardinal;
}

// function to connect to google sheets
bool ConnectToSheets(){
    //Configure time
  configTime(0, 0, ntpServer);

  GSheet.printf("ESP Google Sheet Client v%s\n\n", ESP_GOOGLE_SHEET_CLIENT_VERSION);
// Connect to Wi-Fi
  WiFi.setAutoReconnect(true);
  WiFi.begin(WIFI_SSID, WIFI_PASSWORD);

  Serial.print("Connecting to Wi-Fi");
  int attempts = 0;
  while (WiFi.status() != WL_CONNECTED && attempts < 15) {
    Serial.print(".");
    delay(1000);
    attempts++;
  }

  if(WiFi.status() != WL_CONNECTED){
    Serial.println("\nWiFi Failed. Continuing offline...");
    return false;
  }

  Serial.println();
  Serial.print("Connected with IP: ");
  Serial.println(WiFi.localIP());
  Serial.println();

  // Set the callback for Google API access token generation status (for debug only)
  GSheet.setTokenCallback(tokenStatusCallback);

  // Set the seconds to refresh the auth token before expire (60 to 3540, default is 300 seconds)
  GSheet.setPrerefreshSeconds(10 * 60);

  // Begin the access token generation for Google API authentication
  GSheet.begin(CLIENT_EMAIL, PROJECT_ID, PRIVATE_KEY);
  return true;
}

// gives status of google sheet connetions
void tokenStatusCallback(TokenInfo info){
  
    if (info.status == token_status_error){
        GSheet.printf("Token info: type = %s, status = %s\n", GSheet.getTokenType(info).c_str(), GSheet.getTokenStatus(info).c_str());
        GSheet.printf("Token error: %s\n", GSheet.getTokenError(info).c_str());
        delay(10000);
        WiFi.setSleep(true); 
        Serial.println(WiFi.status());
        Serial.println("");
        ESP.restart();
    }
    else{
        GSheet.printf("Token info: type = %s, status = %s\n", GSheet.getTokenType(info).c_str(), GSheet.getTokenStatus(info).c_str());
    }
}

// function used to reduce json size to append to sheets, for memory reduction for sending.
void addFloat(FirebaseJson &json, const char *path, float value) {
  char buf[16];
  snprintf(buf, sizeof(buf), "%.2f", value);
  json.set(path, buf);
}

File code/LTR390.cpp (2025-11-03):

#include "LTR390.h"

/******************************************************************************
  function:	Send one byte of data to  I2C dev
  parameter:
            Addr: Register address
            Value: Write to the value of the register
  Info:
******************************************************************************/
static void LTR390_Write(UBYTE cmd, UBYTE val)
{
	I2C_Write_Byte(cmd, val);
}

/******************************************************************************
  function:	 read one byte of data to  I2C dev
  parameter:
            Addr: Register address
  Info:
******************************************************************************/
static UBYTE LTR390_Read(UBYTE val)
{
	return I2C_Read_Byte(val);
}


/******************************************************************************
  function:	TSL2591 Initialization
  parameter:
  Info:
******************************************************************************/
UBYTE LTR390_Init(void)
{
	DEV_ModuleInit();
	DEV_I2C_Init(LTR390_ADDR);

	//Serial.print("LTR390 VOC Sensor Init\r\n");

	//ID
	UBYTE Rdata = LTR390_Read(0x06);
    //Serial.println(Rdata);
	if(Rdata != 0xb2) { // 0x3220
		Serial.print("feature set should = 0, but val = 0X");
		Serial.println(Rdata, HEX);
		return 1;
	}

    LTR390_Write(LTR390_MEAS_RATE, RESOLUTION_18BIT_TIME100MS | RATE_100MS);// default
    LTR390_Write(LTR390_GAIN, GAIN_3); //default
    
	return 0;
}

UDOUBLE LTR390_UVS(void)
{
    LTR390_Write(LTR390_INT_CFG, 0x34); // UVS_INT_EN=1, Command=0x34
    LTR390_Write(LTR390_MAIN_CTRL, 0x0A); //  UVS in Active Mode
    UDOUBLE Data1 = LTR390_Read(LTR390_UVSDATA);
    UDOUBLE Data2 = LTR390_Read(LTR390_UVSDATA + 1);
    UDOUBLE Data3 = LTR390_Read(LTR390_UVSDATA + 2);
    UDOUBLE uv;
    uv =  (Data3<<16)| (Data2<<8) | Data1;
    return uv;
}

UDOUBLE LTR390_ALS(void)
{
    LTR390_Write(LTR390_INT_CFG, 0x34); // UVS_INT_EN=1, Command=0x34
    LTR390_Write(LTR390_MAIN_CTRL, 0x0A); //  UVS in Active Mode
    UDOUBLE Data1 = LTR390_Read(LTR390_UVSDATA);
    UDOUBLE Data2 = LTR390_Read(LTR390_UVSDATA + 1);
    UDOUBLE Data3 = LTR390_Read(LTR390_UVSDATA + 2);
    UDOUBLE als;
    als =  (Data3<<16)| (Data2<<8) | Data1;
    return als; 
}

void LTR390_SetIntVal(UDOUBLE low, UDOUBLE high)//LTR390_THRESH_UP and LTR390_THRESH_LOW
{
    LTR390_Write(0x21, high&0xff);
    LTR390_Write(0x22, (high>>8)&0xff);
    LTR390_Write(0x23, (high>>16)&0x0f);
    LTR390_Write(0x24, low&0xff);
    LTR390_Write(0x25, (low>>8)&0xff);
    LTR390_Write(0x26, (low>>16)&0x0f);
}

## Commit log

2025-09-13 Delete Parts/Windvane/WindVane_Print directory
    New Version being uploaded
    [AKMAX_Aeroweather_Windvane_Shaft.3mf, Aeroweather_Windvane_Enclosure.stl, Aeroweather_Windvane_InnerRotor.stl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]
2025-09-13 Adding Mainbox, windvane, and support rod parts
    [EchoWeather_InnerClamp.stl, EchoWeather_Main.f3z, EchoWeather_Main_Bottom.stl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]
2025-09-13 Pipe adapter model
    [EchoWeather_Main_PipeAdapter_.f3d]
2025-09-13 pipe adapter stl
    [EchoWeather_Main_PipeAdapter.stl]
2025-09-20 Updating two stl files to adapt to 4mm steel rod
    [EchoWeather_WindVane_Holder.stl, EchoWeather_WindVane_OuterRotor.stl]
2025-09-20 Updating Fusion models
    [EchoWeather_WindVane.f3z]
2025-09-20 Adding anemometer parts
    [AnemometerBaseCap.stl, AnemometerRotor.stl, AnemometerRotorCap.stl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]
2025-11-03 Adding Wind Cup V3
    Larger diameter and longer reach for more sensitive measurements of wind. The original cups were not sensitive enough and V2 cups were too heavy and big to fit in the existing design.
    [EchoWeather_WindCupv3.stl]
2025-11-03 Wind Cup v3 fusion file
    [EchoWeather_WindCup v3.f3d]
2025-11-03 Add instructions for covering UV and Lux sensors
2025-11-03 Refactor EchoWeather_V1.ino with new sensor integrations
2025-11-03 Uploading Rain Gauge parts
    [EchoWeather_Bucket.stl, EchoWeather_RainGauge.f3z, EchoWeather_RainGauge_BottomGrid.stl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]
2025-11-03 Add Calibration section to README
    Added a section about sensor calibration in progress.
2026-02-19 Refine README content and remove 'WIP' labels
    Updated the README to remove 'WIP' from the title and calibration section, and added details about calibration results.
2026-02-19 Add calibration and changes documentation for weather station
    Documented calibration process and changes made to the weather station after exposure to harsh conditions. Included details on sensor calibrations, repairs, and improvements with a new solar charging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
2026-02-19 Fix image source for Solar Charging Board
    Updated the image source for the Solar Charging Board in the documentation.
2026-02-19 Refactor measurement settings and battery reading
    Updated measurement intervals and calibration factors, commented out sleep functionality, and adjusted battery voltage reading.
2026-02-19 Document changes in charging board and measurement intervals
    Updated the documentation to reflect changes in charging board performance and measurement intervals.
2026-02-19 Revise BOM with new components and costs
    Updated component list and corrected total costs.
    [AeroWeather_BOM.csv]
2026-02-19 Update sensor components and charging module details
2026-03-18 Fixed error looping bug
    This bug has caused the station to become stuck in a loop of reprinting error messages if the internet connection is lost. This code fixes the bug by restarting the system if any errors occur during connection.
    [EchoWeather_V1.ino]
2026-05-02 Change rainPin definition from 9 to 6
    GPIO PIN 9 is a boot strapping pin, this was not a problem until the rain gauge sensor got stuck high, meaning the station could not boot until the sensor arm was physically jostled to loosen the bucket. But it is now on pin 6 which means this problem "should" never happen again.
    [EchoWeather_V1.ino]
2026-05-02 Change rainPin definition from 6 to 21
    I was wrong. It is D6 but gpio 21
    [EchoWeather_V1.ino]
